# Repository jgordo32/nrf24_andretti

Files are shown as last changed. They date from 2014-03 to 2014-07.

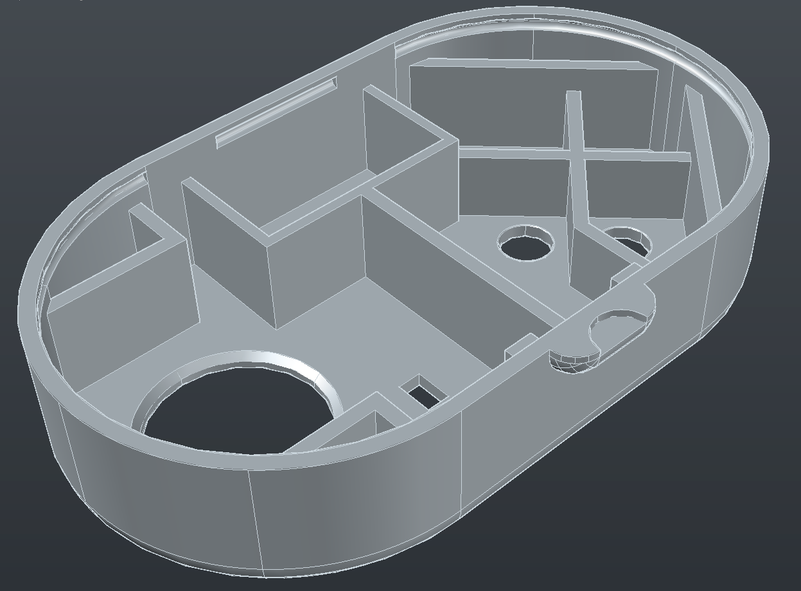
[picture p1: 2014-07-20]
Wireless Controller Case/Renderings/top3.png

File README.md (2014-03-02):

nrf24_andretti
==============

Firmware project for the wireless controllers on the Andretti Video Game Shirt

When the codebase is a little more mature, either each app or each folder will have it's own more thoroughly explained readme file as the FreeRTOS kernel does.

Authors:
Adam Feinstein
Jonathan Gordon

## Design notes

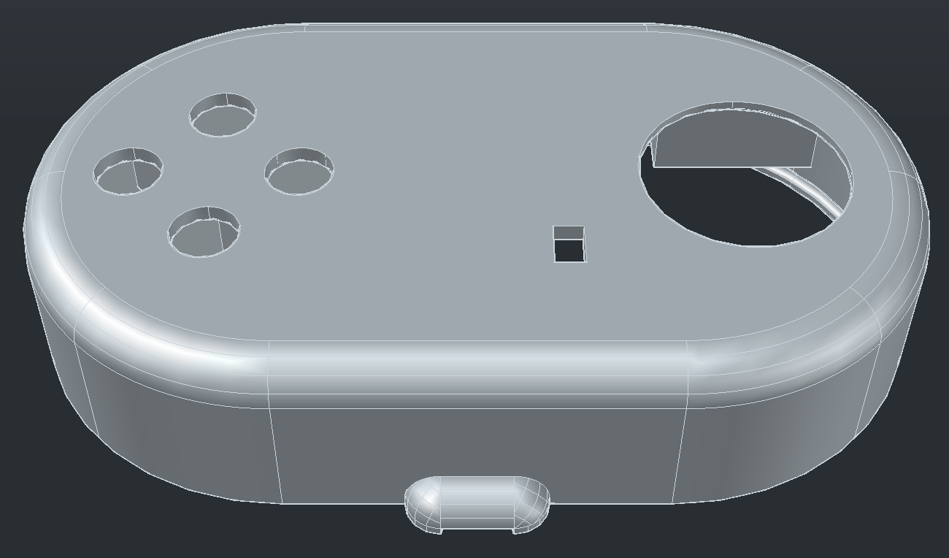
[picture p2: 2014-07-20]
Wireless Controller Case/Renderings/top1.png

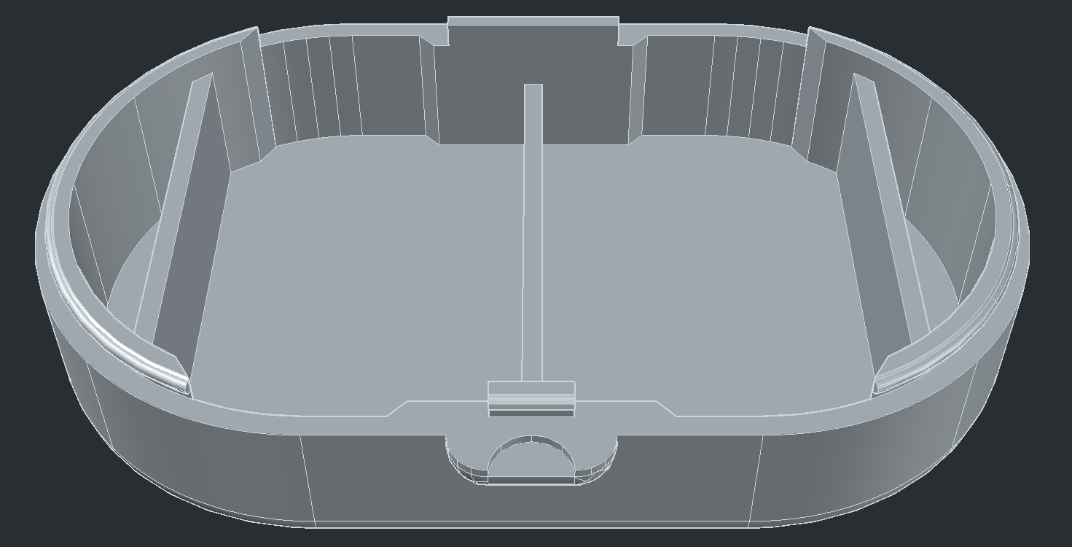
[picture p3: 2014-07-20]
Wireless Controller Case/Renderings/bottom1.png

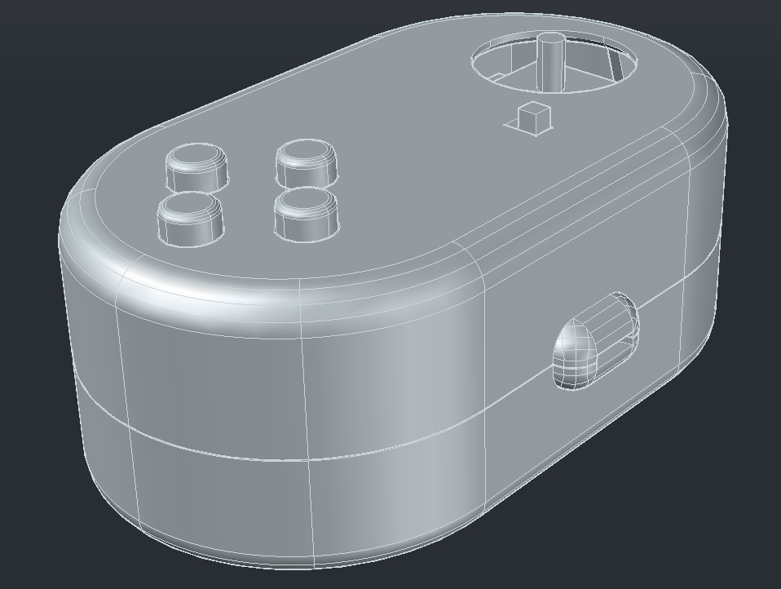
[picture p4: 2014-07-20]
Wireless Controller Case/Renderings/final2.png

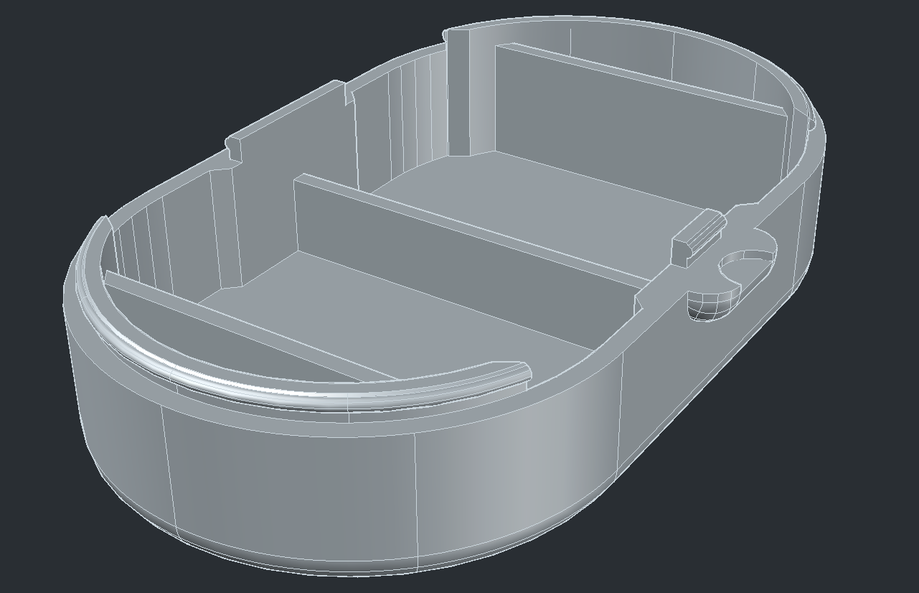
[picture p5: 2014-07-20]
Wireless Controller Case/Renderings/bottom2.png

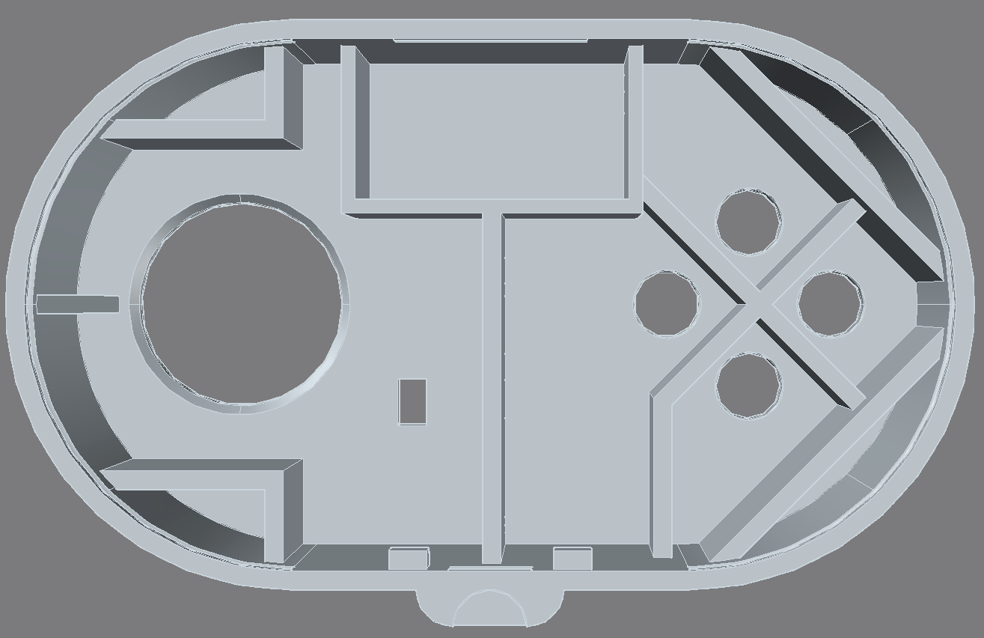
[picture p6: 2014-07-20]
Wireless Controller Case/Renderings/top2.png

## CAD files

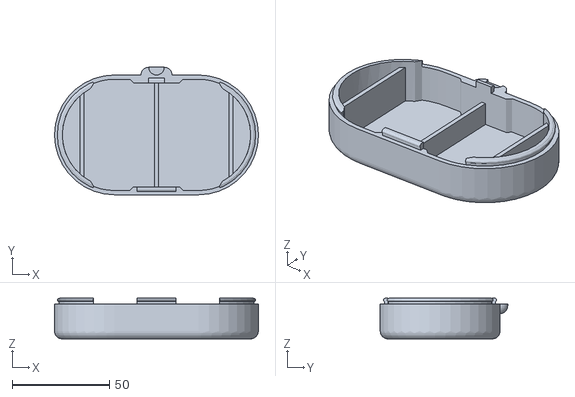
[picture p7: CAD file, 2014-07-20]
Wireless Controller Case/3D print/bottom.stl
104.7 x 65.5 x 21.0

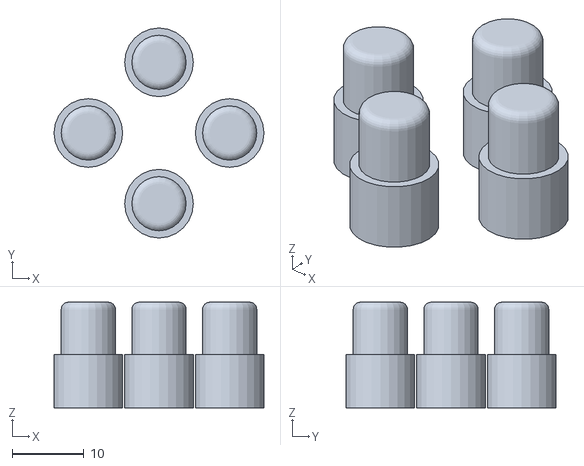
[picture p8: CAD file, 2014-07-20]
Wireless Controller Case/3D print/buttons.stl
29.2 x 29.2 x 14.7

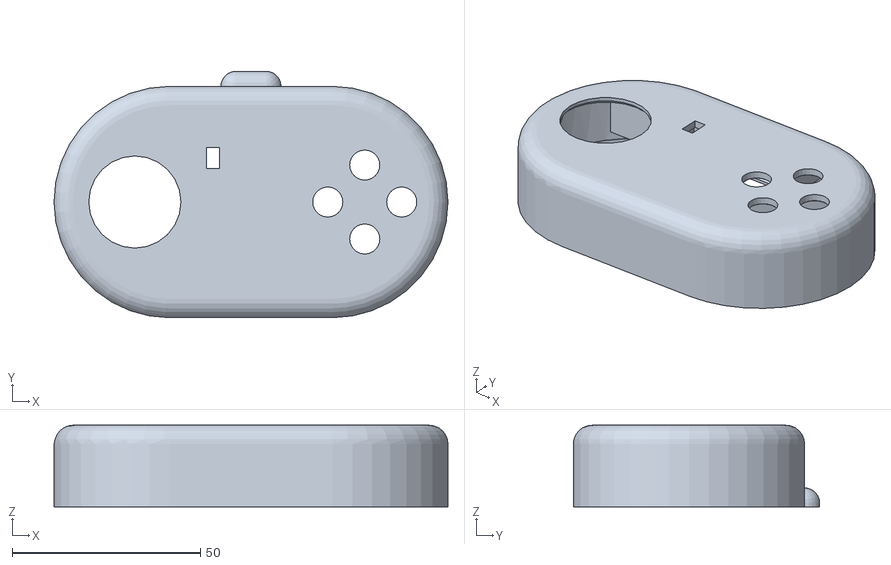
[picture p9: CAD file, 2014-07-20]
Wireless Controller Case/3D print/top.stl
104.7 x 65.5 x 21.7

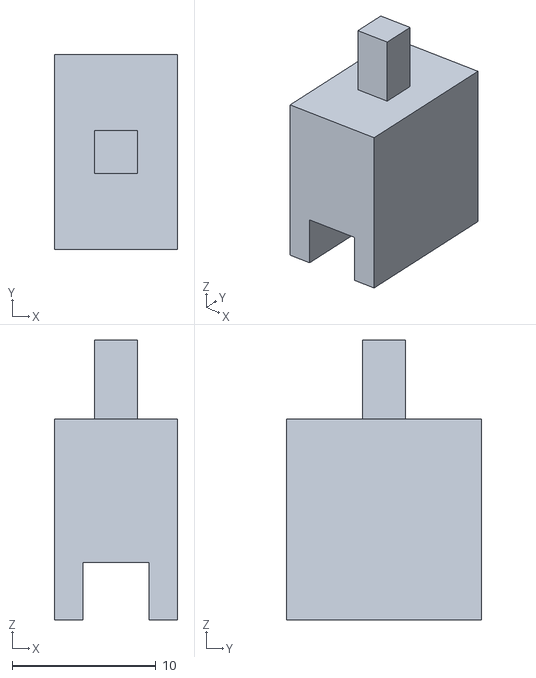
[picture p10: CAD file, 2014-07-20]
Wireless Controller Case/3D print/switch.stl
8.60 x 13.6 x 19.5

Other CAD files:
Wireless Controller Case/controller_case.dwg

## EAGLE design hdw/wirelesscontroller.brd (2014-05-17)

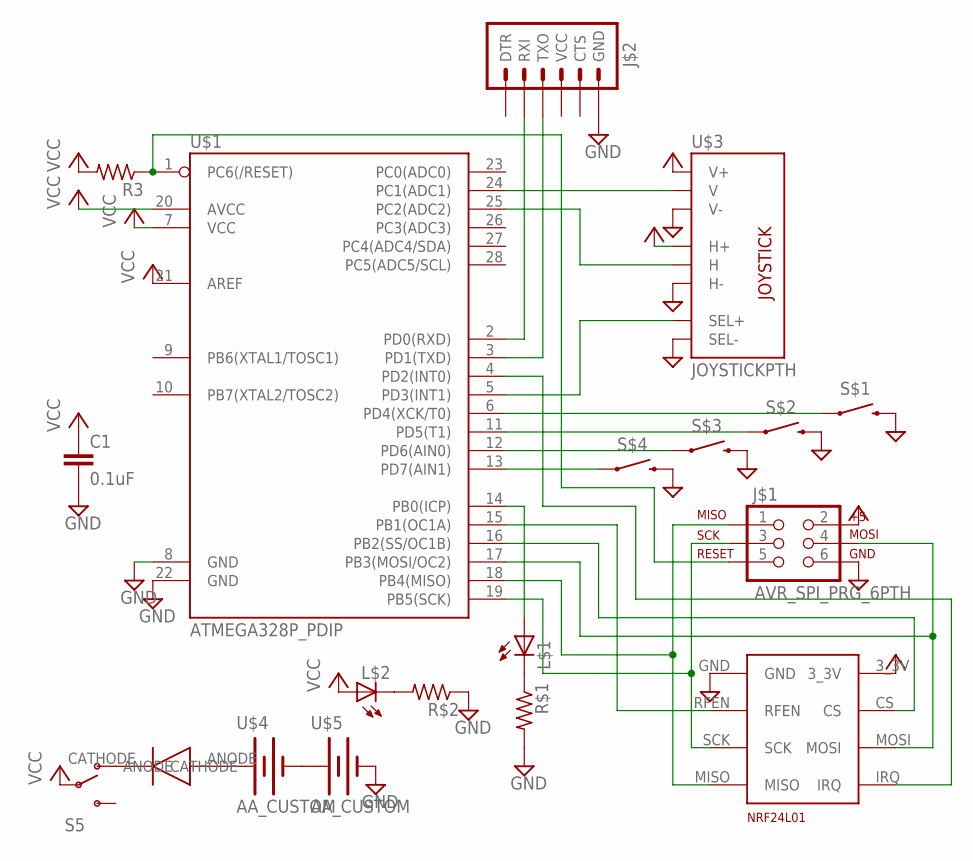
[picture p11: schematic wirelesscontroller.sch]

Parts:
C1: 0.1uF; 0603-CAP
D$1: DIODE; R0603
J$1: AVR_SPI_PRG_6PTH; 2X3
J$2: ARDUINO_SERIAL_PROGRAMPTH; 1X06
L$1, L$2: LEDCHIPLED_0603; CHIPLED_0603
R3: R-US_R0603; R0603
R$1, R$2: R-US_R0603; R0603
S5: SWITCH-SPDTPTH; SWITCH-SPDT
S$1, S$2, S$3, S$4: SWITCH-MOMENTARY-212MM; TACTILE-PTH-12MM
U$1: ATMEGA328P_PDIP; DIL28-3
U$2: NRF24L01_BRK; 4X2
U$3: JOYSTICKPTH; JOYSTICK
U$4, U$5: AA_CUSTOM; AACLIP

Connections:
AX: U$1.25 (PC2(ADC2)), U$3.H2 (H)
AY: U$1.24 (PC1(ADC1)), U$3.V2 (V)
B1: S$1.1, U$1.6 (PD4(XCK/T0))
B2: S$2.1, U$1.11 (PD5(T1))
B3: S$3.1, U$1.12 (PD6(AIN0))
B4: S$4.1, U$1.13 (PD7(AIN1))
B5: U$1.5 (PD3(INT1)), U$3.B1A (SEL+)
CS: U$1.16 (PB2(SS/OC1B)), U$2.CS
GND: C1.2, J$1.6, J$2.6 (GND), R$1.2, R$2.1, S$1.3 (2), S$2.3 (2), S$3.3 (2), S$4.3 (2), U$1.8 (GND), U$1.22 (GND), U$2.GND, U$3.B2A (SEL-), U$3.H3 (H-), U$3.V3 (V-), U$5.-
MISO: J$1.1, U$1.18 (PB4(MISO)), U$2.MISO
MOSI: J$1.4, U$1.17 (PB3(MOSI/OC2)), U$2.MOSI
unnamed: D$1.CATHODE, S5.1 (O)
unnamed: U$4.-, U$5.+
unnamed: D$1.ANODE, U$4.+
unnamed: L$2.C, R$2.2
unnamed: L$1.C, R$1.1
unnamed: L$1.A, U$1.14 (PB0(ICP))
RESET: J$1.5, R3.1, U$1.1 (PC6(/RESET))
RFEN: U$1.15 (PB1(OC1A)), U$2.RFEN
RF_IRQ: U$1.4 (PD2(INT0)), U$2.IRQ
RX: J$2.2 (RXI), U$1.2 (PD0(RXD))
SCK: J$1.3, U$1.19 (PB5(SCK)), U$2.SCK
TX: J$2.3 (TXO), U$1.3 (PD1(TXD))
VCC: C1.1, J$1.2, L$2.A, R3.2, S5.2, U$1.7 (VCC), U$1.20 (AVCC), U$1.21 (AREF), U$2.3_3V, U$3.H1 (H+), U$3.V1 (V+)

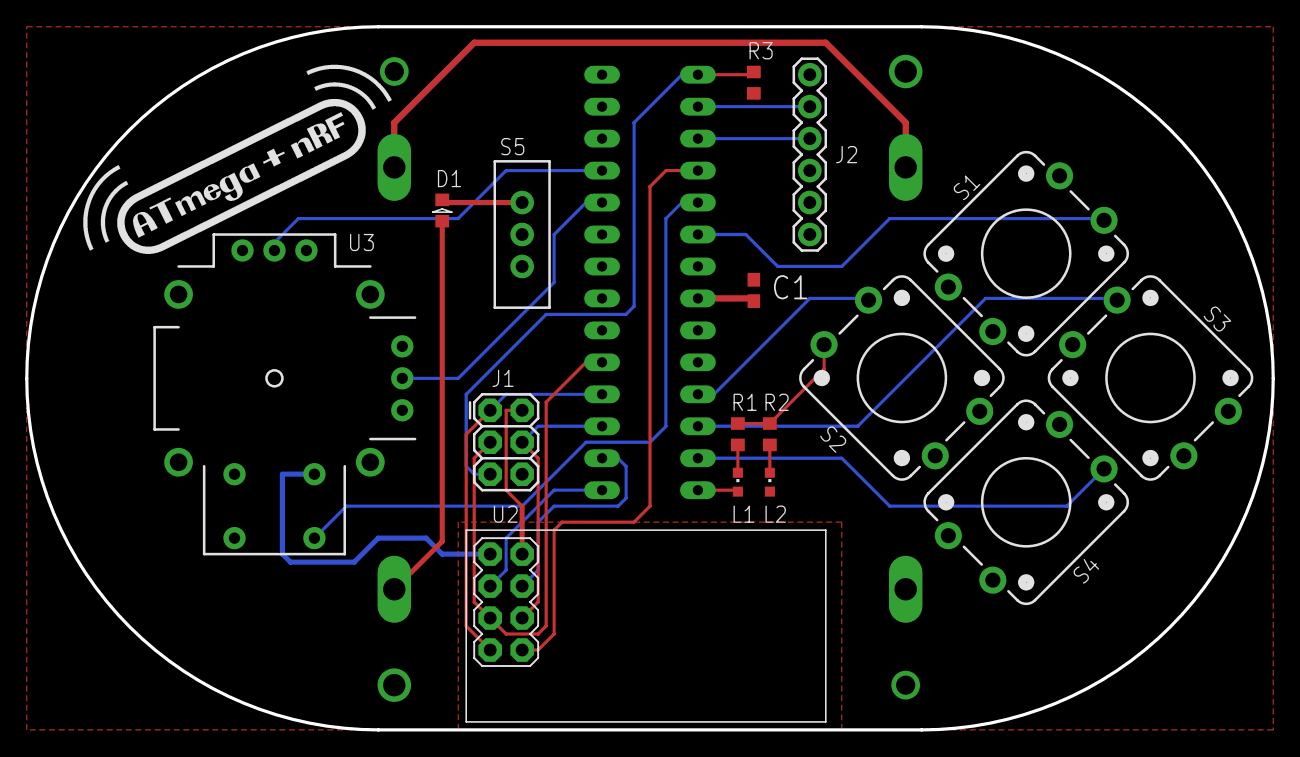
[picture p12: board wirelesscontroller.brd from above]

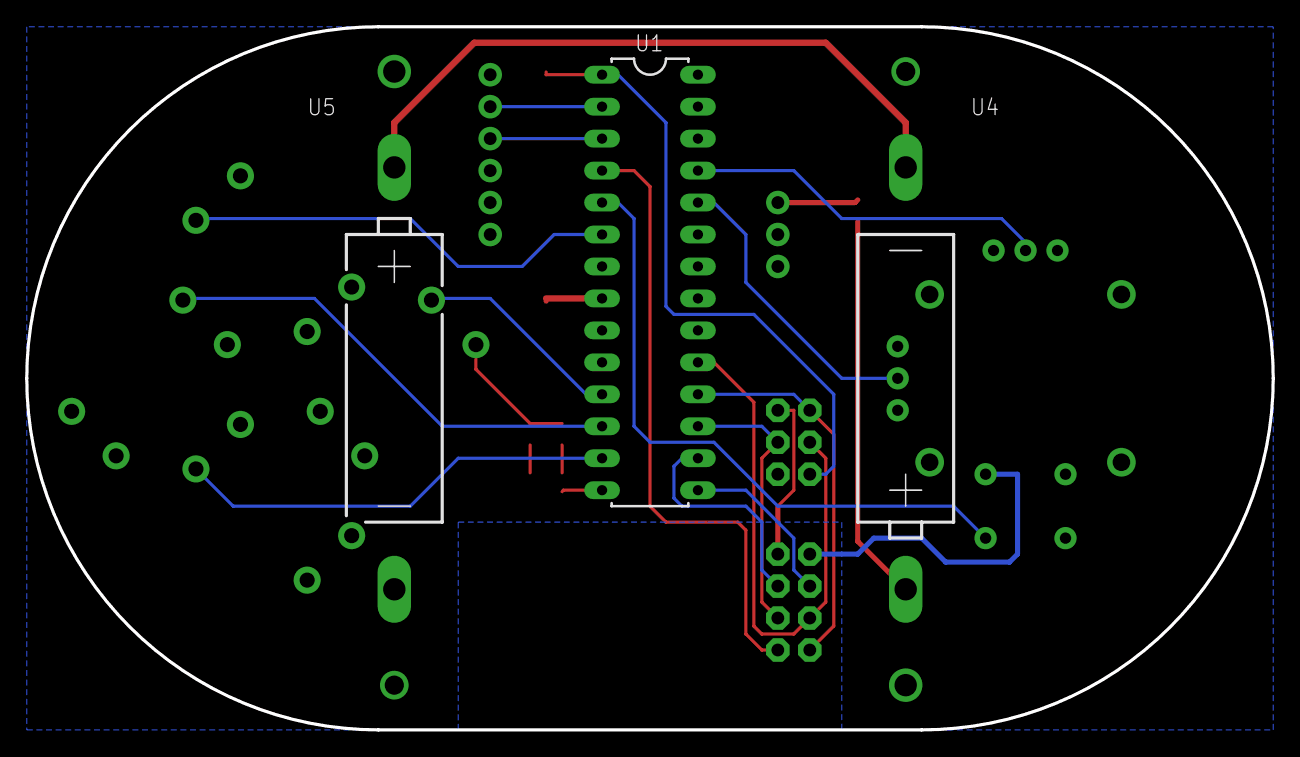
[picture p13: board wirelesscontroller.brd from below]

Board: 2 copper layers, 99.1 x 55.9 mm, 19 parts (3 on the bottom side), 24 nets.

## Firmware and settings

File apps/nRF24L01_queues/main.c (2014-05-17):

////////////////////////////////////////////////////////
////////////////////////////////////////////////////////
////    main.c 
////////////////////////////////////////////////////////
////////////////////////////////////////////////////////

#include <stdlib.h>
#include <string.h>
#include <math.h>
#include <stdio.h>
#include <avr/io.h>
#include <avr/pgmspace.h>
#include <util/delay.h>

/* Scheduler include files */
#include "FreeRTOS.h"
#include "task.h"
#include "queue.h"
#include "semphr.h"

/* Application specific includes */
#include "nrf24.h"
#include "config_types.h"

/* Local Function Prototypes */
void initPorts(void);
void initTimers(void);
void initRadio(void);

void taskHeartbeat2(void *pvParameters);
void radioTask(void *pvParameters);

static int uart_putchar(char c, FILE * stream);
static FILE debug_out = FDEV_SETUP_STREAM(uart_putchar, NULL, _FDEV_SETUP_WRITE);

/* Queue to hold rf transfer data */
xQueueHandle rfQueue;

//TODO: optimize these
/* nrf24 configuration parameters */
#define NRF24_CHANNEL_MHZ		15
#define NRF24_PAYLOAD_LEN		4

#if(BOARD_CONFIG == ARDUINO)
uint8_t ptxAddr[5] = {0xE7, 0xE7, 0xE7, 0xE7, 0xE7};
uint8_t prxAddr[5] = {0xD1, 0xD1, 0xD1, 0xD1, 0xD1};
#elif(BOARD_CONFIG == AVR)
uint8_t ptxAddr[5] = {0xD1, 0xD1, 0xD1, 0xD1, 0xD1};
uint8_t prxAddr[5] = {0xE7, 0xE7, 0xE7, 0xE7, 0xE7};
#endif

/* Main program loop */
int main(void)
{
    
#if 1
    /* Hardware initialization */
    initPorts();
    
    initTimers();
    initRadio();

    rfQueue = xQueueCreate(64, sizeof(uint8_t));  //64 byte queue for RF transfer data

    xTaskCreate(radioTask, (const signed portCHAR *)"Radio", 218, NULL, 2, NULL);
    xTaskCreate(taskHeartbeat2, (const signed portCHAR *)"Blink2", 48, NULL, 1, NULL);


    vTaskStartScheduler();
#else
    //Make PortB.0 an output
    DDRB |= _BV(0);
    while(1)
    {
        // Toggle PortB.0
        PORTB ^= _BV(0);
        _delay_ms(500);
    }    

    
#endif

    return 0;
}

void initRadio(void){
	nrf24_init();
	nrf24_config(NRF24_CHANNEL_MHZ, NRF24_PAYLOAD_LEN);//channel 15, 16 byte payload
	nrf24_tx_address(ptxAddr);
	nrf24_rx_address(prxAddr);

}

/* Blink the LED on PORTC.0 @ 1 Hz */
void taskHeartbeat2(void *pvParameters)
{
	(void) pvParameters;
	uint8_t odd = 0;
	const portTickType xDelay = 500 / portTICK_RATE_MS;
	while(1){
		if(odd)
			PORTB |= _BV(PORTB0);
		else
			PORTB &= ~_BV(PORTB0);
		odd = !odd;
		vTaskDelay(xDelay);
		printf("Heart-beat!\n");
	}
}

/* Send data using the nRF radio */
void radioTask(void *pvParameters)
{
	(void) pvParameters;
	uint8_t rfData[NRF24_PAYLOAD_LEN];
	uint8_t rcvData[NRF24_PAYLOAD_LEN];
	uint8_t pktCounter = 0;
	uint8_t blinkCounter = 0;
	const portTickType blinkDelay = 250 / portTICK_RATE_MS;
	const portTickType sendDelay = 5000 / portTICK_RATE_MS;

	rfData[0] = 0xB1;
	rfData[1] = 0x3A;
	rfData[2] = 0x23;
	while(1)
	{
		if(nrf24_dataReady())
		{
			nrf24_getData(rcvData);
			// Format message for debugging
			char debugRcvString[3*6] = {0};
			for (uint8_t i=0; i < NRF24_PAYLOAD_LEN; i++)
			{
				sprintf(debugRcvString+(3*i), "%02X ", rcvData[i]);
			}
			printf("Received: %s\n", debugRcvString);
		}


		rfData[3] = pktCounter++;
		nrf24_send(rfData);
		while(nrf24_isSending());
		char debugSendString[3*6] = {0};
		for (uint8_t i = 0; i < NRF24_PAYLOAD_LEN; i++)
		{
			sprintf(debugSendString+(3*i), "%02X ", rfData[i]);
		}
		printf("Sent: %s\n", debugSendString);

		if(nrf24_lastMessageStatus())
		{
			//there was a send problem
		}else{
			//transmission was ok
		}
		for(blinkCounter = 1 + nrf24_retransmissionCount(); blinkCounter > 0; --blinkCounter)
		{
			PORTC |= _BV(PORTC3);
			vTaskDelay(blinkDelay);
			PORTC &= ~_BV(PORTC3);
			vTaskDelay(blinkDelay);

		}

		nrf24_powerUpRx();
		vTaskDelay(sendDelay);

	}
}

/* Initialization Functions */

/* Init Ports */
void initPorts(void){
	// Port B initialization
    // 0 - output 	- LED
    // 1 - output 	- rfen						- nRF CE
    // 2 - output 	- /SS						- nRF CSN
    // 3 - output  	- MOSI						- nRF MOSI
    // 4 - input 	- MISO						- nRF MISO
    // 5 - output 	- SCK and arduino LED		- nRF SCK
    // 6 - output 	- NC
    // 7 - output 	- NC

	// DDRB
    // 0b1110 1111 	= 0xEF
	PORTB = 0x00;
	DDRB = 0xEF;

	/* Initialize the hardware SPI module after setting the /SS to output */
	SPCR |= (_BV(MSTR) | _BV(SPE)); //set to master and enable //enabling SPI messes up arduino LED which is on SCK line
	SPCR &= ~(_BV(CPOL) | _BV(CPHA) | _BV(DORD) | _BV(SPR0) | _BV(SPR1)); //set to mode0 with MSB first, f_clk/4
	SPSR |= SPI2X; //this divides min clk cycles by 2 so now SCK = f_clk/2


	// Port C initialization
    // 0 - output 	- NC
    // 1 - input 	- V potentiometer
    // 2 - input 	- H potentiometer
    // 3 - output 	- NC
    // 4 - output 	- NC
    // 5 - output 	- NC
    // 6 - input 	- pulled up, /RESET
    // 7 - output 	- NC

	// DDRC
	// 0b1011 1001	= 0xB9
	PORTC = 0x00;
	DDRC = 0xB9;

	// Port D initialization
    // 0 - input  	- uart RX
    // 1 - output  	- uart TX
    // 2 - input  	- RF interrupt INT0			- nRF IRQ
    // 3 - input 	- joystick button
    // 4 - input  	- button 1
    // 5 - input  	- button 2
    // 6 - input  	- button 3
    // 7 - input  	- button 4
    // NOTE: all buttons need to use internal pull-ups

	// DDRD
    // 0b0000 0010 	= 0x02
   	PORTD = 0x00;
	DDRD = 0x02;
    PORTD = 0xF8; /* Enable pull-ups on the highest 5 pins for the buttons */

	//TODO: don't hardcode this... make it baudrate generic from build settings maybe?
	/* Initialize the hardware UART */
	/* Set baud */
	uint16_t ubrr = 0;
#if(BOARD_CONFIG == ARDUINO)
	ubrr = ((configCPU_CLOCK_HZ / 16) / 57600) - 1;
#elif(BOARD_CONFIG == AVR)
	ubrr = ((configCPU_CLOCK_HZ / 16) / 4800) - 1;
#endif
	UBRR0H = (uint8_t)(ubrr >> 8);
	UBRR0L = (uint8_t)(ubrr);
	/* Enable the receiver and transmitter */
	UCSR0B = (_BV(RXEN0) | _BV(TXEN0));
	/* Set framing to 8N1 */
	UCSR0C = (_BV(UCSZ00) | _BV(UCSZ01));

	/* Initialize the global stream stdout */
	stdout = &debug_out;
}

/* Init Timers */
void initTimers(void){
	// Timer/Counter 0 initialization
	// Clock source: System Clock
	// Clock value: Timer 0 Stopped
	// Mode: Normal top=FFh
	// OC0 output: Disconnected
	// ASSR=0x00;
	// TCCR0=0x00;
	// TCNT0=0x00;
	// OCR0=0x00;

	// Timer/Counter 1 initialization
	// Mode: Normal top=FFFFh


	// OC1A output: Discon.
	// OC1B output: Discon.
	// OC1C output: Discon.
	TCCR1A=0x00;

	// Clock source: none               = 00
	// Clock source: system clock       = 01
	// Clock source: system clock/64    = 03
	// Clock source: system clock/256   = 04
	// Clock source: system clock/1024  = 05
	// Noise Canceler: Off
	// Input Capture on Falling Edge
	TCCR1B=0x00;

    // set the inital counts to zero
	TCNT1H=0x00;
	TCNT1L=0x00;

    // amount to compare the timer to
	OCR1AH=0x00;
	OCR1AL=0x00;

	OCR1BH=0x00;
	OCR1BL=0x00;


	// Timer/Counter 2 initialization
	// Clock source: T2 pin Rising Edge
	// Mode: Normal top=FFh
	// OC2 output: Disconnected
	TCCR2B=0x07;
	TCNT2=0x00;
	OCR2A=0x00;

}

/* Printing to UART function */
static int uart_putchar(char c, FILE * stream)
{
	if (c == '\n')
		uart_putchar('\r', stream);
	while(!(UCSR0A & _BV(UDRE0)));

    UDR0 = c;
    return 0;
}

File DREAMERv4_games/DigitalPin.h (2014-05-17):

/* Arduino DigitalPin Library
 * Copyright (C) 2012 by William Greiman
 *
 * This file is part of the Arduino DigitalPin Library
 *
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
 * You should have received a copy of the GNU General Public License
 * along with the Arduino DigitalPin Library.  If not, see
 * <http://www.gnu.org/licenses/>.
 */
/**
 * \file
 * \brief DigitalPin class
 */
#ifndef DigitalPin_h
#define DigitalPin_h
#include <avr/io.h>
#include <util/atomic.h>
//------------------------------------------------------------------------------
/** DigitalPin version YYYYMMDD */
#define DIGITAL_PIN_VERSION 20120804
//------------------------------------------------------------------------------
/**
 * \class pin_map_t
 * \brief struct for mapping digital pins
 */
struct pin_map_t {
  volatile uint8_t* ddr;   /**< address of DDR for this pin */
  volatile uint8_t* pin;   /**< address of PIN for this pin */
  volatile uint8_t* port;  /**< address of PORT for this pin */
  uint8_t bit;             /**< bit number for this pin */
};
//------------------------------------------------------------------------------
#if defined(__AVR_ATmega168__)\
||defined(__AVR_ATmega168P__)\
||defined(__AVR_ATmega328P__)
// 168 and 328 Arduinos
const static pin_map_t pinMap[] = {
  {&DDRD, &PIND, &PORTD, 0},  // D0  0
  {&DDRD, &PIND, &PORTD, 1},  // D1  1
  {&DDRD, &PIND, &PORTD, 2},  // D2  2
  {&DDRD, &PIND, &PORTD, 3},  // D3  3
  {&DDRD, &PIND, &PORTD, 4},  // D4  4
  {&DDRD, &PIND, &PORTD, 5},  // D5  5
  {&DDRD, &PIND, &PORTD, 6},  // D6  6
  {&DDRD, &PIND, &PORTD, 7},  // D7  7
  {&DDRB, &PINB, &PORTB, 0},  // B0  8
  {&DDRB, &PINB, &PORTB, 1},  // B1  9
  {&DDRB, &PINB, &PORTB, 2},  // B2 10
  {&DDRB, &PINB, &PORTB, 3},  // B3 11
  {&DDRB, &PINB, &PORTB, 4},  // B4 12
  {&DDRB, &PINB, &PORTB, 5},  // B5 13
  {&DDRC, &PINC, &PORTC, 0},  // C0 14
  {&DDRC, &PINC, &PORTC, 1},  // C1 15
  {&DDRC, &PINC, &PORTC, 2},  // C2 16
  {&DDRC, &PINC, &PORTC, 3},  // C3 17
  {&DDRC, &PINC, &PORTC, 4},  // C4 18
  {&DDRC, &PINC, &PORTC, 5}   // C5 19
};
//------------------------------------------------------------------------------
#elif defined(__AVR_ATmega1280__)\
|| defined(__AVR_ATmega2560__)
// Mega
static const pin_map_t pinMap[] = {
  {&DDRE, &PINE, &PORTE, 0},  // E0  0
  {&DDRE, &PINE, &PORTE, 1},  // E1  1
  {&DDRE, &PINE, &PORTE, 4},  // E4  2
  {&DDRE, &PINE, &PORTE, 5},  // E5  3
  {&DDRG, &PING, &PORTG, 5},  // G5  4
  {&DDRE, &PINE, &PORTE, 3},  // E3  5
  {&DDRH, &PINH, &PORTH, 3},  // H3  6
  {&DDRH, &PINH, &PORTH, 4},  // H4  7
  {&DDRH, &PINH, &PORTH, 5},  // H5  8
  {&DDRH, &PINH, &PORTH, 6},  // H6  9
  {&DDRB, &PINB, &PORTB, 4},  // B4 10
  {&DDRB, &PINB, &PORTB, 5},  // B5 11
  {&DDRB, &PINB, &PORTB, 6},  // B6 12
  {&DDRB, &PINB, &PORTB, 7},  // B7 13
  {&DDRJ, &PINJ, &PORTJ, 1},  // J1 14
  {&DDRJ, &PINJ, &PORTJ, 0},  // J0 15
  {&DDRH, &PINH, &PORTH, 1},  // H1 16
  {&DDRH, &PINH, &PORTH, 0},  // H0 17
  {&DDRD, &PIND, &PORTD, 3},  // D3 18
  {&DDRD, &PIND, &PORTD, 2},  // D2 19
  {&DDRD, &PIND, &PORTD, 1},  // D1 20
  {&DDRD, &PIND, &PORTD, 0},  // D0 21
  {&DDRA, &PINA, &PORTA, 0},  // A0 22
  {&DDRA, &PINA, &PORTA, 1},  // A1 23
  {&DDRA, &PINA, &PORTA, 2},  // A2 24
  {&DDRA, &PINA, &PORTA, 3},  // A3 25
  {&DDRA, &PINA, &PORTA, 4},  // A4 26
  {&DDRA, &PINA, &PORTA, 5},  // A5 27
  {&DDRA, &PINA, &PORTA, 6},  // A6 28
  {&DDRA, &PINA, &PORTA, 7},  // A7 29
  {&DDRC, &PINC, &PORTC, 7},  // C7 30
  {&DDRC, &PINC, &PORTC, 6},  // C6 31
  {&DDRC, &PINC, &PORTC, 5},  // C5 32
  {&DDRC, &PINC, &PORTC, 4},  // C4 33
  {&DDRC, &PINC, &PORTC, 3},  // C3 34
  {&DDRC, &PINC, &PORTC, 2},  // C2 35
  {&DDRC, &PINC, &PORTC, 1},  // C1 36
  {&DDRC, &PINC, &PORTC, 0},  // C0 37
  {&DDRD, &PIND, &PORTD, 7},  // D7 38
  {&DDRG, &PING, &PORTG, 2},  // G2 39
  {&DDRG, &PING, &PORTG, 1},  // G1 40
  {&DDRG, &PING, &PORTG, 0},  // G0 41
  {&DDRL, &PINL, &PORTL, 7},  // L7 42
  {&DDRL, &PINL, &PORTL, 6},  // L6 43
  {&DDRL, &PINL, &PORTL, 5},  // L5 44
  {&DDRL, &PINL, &PORTL, 4},  // L4 45
  {&DDRL, &PINL, &PORTL, 3},  // L3 46
  {&DDRL, &PINL, &PORTL, 2},  // L2 47
  {&DDRL, &PINL, &PORTL, 1},  // L1 48
  {&DDRL, &PINL, &PORTL, 0},  // L0 49
  {&DDRB, &PINB, &PORTB, 3},  // B3 50
  {&DDRB, &PINB, &PORTB, 2},  // B2 51
  {&DDRB, &PINB, &PORTB, 1},  // B1 52
  {&DDRB, &PINB, &PORTB, 0},  // B0 53
  {&DDRF, &PINF, &PORTF, 0},  // F0 54
  {&DDRF, &PINF, &PORTF, 1},  // F1 55
  {&DDRF, &PINF, &PORTF, 2},  // F2 56
  {&DDRF, &PINF, &PORTF, 3},  // F3 57
  {&DDRF, &PINF, &PORTF, 4},  // F4 58
  {&DDRF, &PINF, &PORTF, 5},  // F5 59
  {&DDRF, &PINF, &PORTF, 6},  // F6 60
  {&DDRF, &PINF, &PORTF, 7},  // F7 61
  {&DDRK, &PINK, &PORTK, 0},  // K0 62
  {&DDRK, &PINK, &PORTK, 1},  // K1 63
  {&DDRK, &PINK, &PORTK, 2},  // K2 64
  {&DDRK, &PINK, &PORTK, 3},  // K3 65
  {&DDRK, &PINK, &PORTK, 4},  // K4 66
  {&DDRK, &PINK, &PORTK, 5},  // K5 67
  {&DDRK, &PINK, &PORTK, 6},  // K6 68
  {&DDRK, &PINK, &PORTK, 7}   // K7 69
};
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

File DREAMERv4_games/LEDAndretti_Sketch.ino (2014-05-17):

#include <SPI.h>
#include "DigitalPin.h"
#include "ArduinoGame.h"
#include "Pong.h"
#include "Lightcycle.h"
#include "Life.h"
#include "TicTacToe.h"
#include "Tetris.h"
#include "ArduinoGame.h"

#define HEARTBEAT_IN_MAIN
//#define TEST_PATTERN
//#define SERIAL_PRINT
//#define IRQ_ENABLED

#define NUM_GAMES 5

#define PONG 0
#define TETRIS 1
#define LIGHTCYCLE 2
#define TICTACTOE 3
#define GAMEOFLIFE 4

unsigned char gameMode;
unsigned char downTimer;

#ifndef IRQ_ENABLED
unsigned long microsTimer;
unsigned long currTime;
#endif

// Function Declarations
void LEDShiftOut(byte IC5, byte IC3, byte IC4, byte IC6);
void UpdateGame(void);

// Variable Declarations
DigitalPin<7> latchPin;
DigitalPin<13> lightPin;

DigitalPin<P1_BL> p1bl;
DigitalPin<P1_BR> p1br;
DigitalPin<P1_BU> p1bu;
DigitalPin<P1_BD> p1bd;
DigitalPin<P2_BL> p2bl;
DigitalPin<P2_BR> p2br;
DigitalPin<P2_BU> p2bu;
DigitalPin<P2_BD> p2bd;

// LED field, currently treated as boolean, maybe brightness one day. Can PWM up to 1/8 without much flicker!
volatile unsigned char field[BOARD_SIZE][BOARD_SIZE];

// Heartbeat variables
unsigned long lastTick;
unsigned int toggle;

// Used for drawing the field
int i, j;
byte IC3, IC4, IC5, IC6;
unsigned long PWMcnt;

#ifdef TEST_PATTERN
int testCnt;
#endif

// Manage the Games
ArduinoGame* currentGame;

Pong pong;
Lightcycle lightcycle;
GameOfLife gameoflife;
TicTacToe tictactoe;
Tetris tetris;

void setup()
{
#ifdef SERIAL_PRINT
  Serial.begin(115200);
#endif

  // Seed the RNG
  randomSeed(analogRead(RANDOM_PIN));

  // Clear Variables
  memset((void*)field, 0, sizeof(field));
  lastTick = 0;
  toggle = 0;
  downTimer = 0;
  PWMcnt = 0;
#ifndef IRQ_ENABLED
  microsTimer = 0;
#endif

  gameMode = PONG;
  currentGame = &pong;
  currentGame->ResetGame(field,1,0);

#ifdef TEST_PATTERN
  testCnt = 0;
#endif

  // Enable pins
  latchPin.mode(OUTPUT);
  lightPin.mode(OUTPUT);

  // Internal pullups
  p1bl.mode(INPUT);
  p1bl.high();
  p1br.mode(INPUT);
  p1br.high();
  p1bu.mode(INPUT);
  p1bu.high();
  p1bd.mode(INPUT);
  p1bd.high();
  p2bl.mode(INPUT);
  p2bl.high();
  p2br.mode(INPUT);
  p2br.high();
  p2bu.mode(INPUT);
  p2bu.high();
  p2bd.mode(INPUT);
  p2bd.high();

  // initialize SPI:
  SPI.begin();
  SPI.setClockDivider(SPI_CLOCK_DIV2); // 8MHz

#ifdef IRQ_ENABLED
  // Set up interrupt
  cli();//stop interrupts
  toggle = 0;

  //set timer1 interrupt at IRQ_HZ Hz
  TCCR1A = 0;// set entire TCCR1A register to 0
  TCCR1B = 0;// same for TCCR1B
  TCNT1 = 0;//initialize counter value to 0
  // set compare match register for 1hz increments
  OCR1A = 15625/IRQ_HZ - 1;// (must be <65536) [16MHz / (1024 * IRQ_HZ) - 1]
  // turn on CTC mode
  TCCR1B |= (1 << WGM12);
  // Set CS10 and CS12 bits for 1024 prescaler
  TCCR1B |= (1 << CS12) | (1 << CS10);
  // enable timer compare interrupt
  TIMSK1 |= (1 << OCIE1A);

  sei();//allow interrupts
#endif
}

void loop()
{

#ifdef HEARTBEAT_IN_MAIN
  if(lastTick + 500 < millis()) {
    lastTick = millis();
    if(toggle == 1) {
      toggle = 0;
      lightPin.low();
    }
    else {
      toggle = 1;
      lightPin.high();
    }
  }
#endif

#ifndef IRQ_ENABLED
  currTime = micros();
  if(microsTimer + 1000000/IRQ_HZ < currTime) {
    // Clear the screen for processing
    LEDShiftOut(0x00, 0xFF, 0xFF, 0x00);
    microsTimer = currTime;
    UpdateGame();
  }
#endif
  // Writes 32 bits, 256 times, for a total of 8192 bits. @8MHz SPI, thats 1.024ms.
  // But we have to toggle the latch too, so each set of 32 bits takes 14.76 uS, for a total of 3.78ms
  // This interrupt can be called at most 264Hz (312Hz experimentally, but the LEDs slow down)

  // Iterate through all possible LEDs, flash them if they are on
  for (i = 0; i < BOARD_SIZE; i++) { // X axis, controls VCC
    for (j = 0; j < BOARD_SIZE; j++) { // Y axis, controls GND
      if (field[i][j] /*&& (PWMcnt % field[i][j] == 0)*/) {
        // GND, LSB
        IC3 = ((~(0x8000 >> j)) >> 8) & 0xFF;
        IC4 = ((~(0x8000 >> j)) >> 0) & 0xFF;

        // VCC, MSB
        IC5 = ((0x0001 << i) >> 0) & 0xFF;
        IC6 = ((0x0001 << i) >> 8) & 0xFF;

        LEDShiftOut(IC5, IC3, IC4, IC6);
      }
      else {
        LEDShiftOut(0x00, 0xFF, 0xFF, 0x00);
      }
    }
  }
  PWMcnt++;
}

#ifdef IRQ_ENABLED
//timer1 interrupt 60Hz
ISR(TIMER1_COMPA_vect)
{
  cli();// stop interrupts
  LEDShiftOut(0x00, 0xFF, 0xFF, 0x00);

  // Heartbeat
#ifndef HEARTBEAT_IN_MAIN
  toggle++;
  if (toggle == IRQ_HZ/2) {
    lightPin.high();
  }
  else if(toggle == IRQ_HZ) {
    lightPin.low();
    toggle = 0;
  }
#endif

  UpdateGame();

  sei();// enable interrupts
}
#endif

// First byte controls VCC towards jack
// Second byte controls GND towards jack
// Third byte controls GND away from jack
// Last byte controls VCC away from jack
void LEDShiftOut(byte IC5, byte IC3, byte IC4, byte IC6)
{
  // take the SS pin low to select the chip:
  latchPin.low(); // latch is held low for 14.76 uS
  // send in the address and value via SPI:
  SPI.transfer(IC5);
  SPI.transfer(IC3);
  SPI.transfer(IC4);
  SPI.transfer(IC6);
  // take the SS pin high to de-select the chip:
  latchPin.high();
}

void UpdateGame(void)
{

#ifdef TEST_PATTERN
  field[testCnt%BOARD_SIZE][testCnt/BOARD_SIZE] = 0;
  testCnt = (testCnt+1)%(BOARD_SIZE*BOARD_SIZE);
  field[testCnt%BOARD_SIZE][testCnt/BOARD_SIZE] = 0xFF;
#else

  if(!p1bu.read() && !p2bu.read()) {
    downTimer++;
  }
  else {
    downTimer = 0;
  }

  if(downTimer == IRQ_HZ * 2) {
    downTimer = 0;
    gameMode = (gameMode+1)%NUM_GAMES;
    switch(gameMode) {
      case PONG:
        currentGame = &pong;
        break;
      case LIGHTCYCLE:
        currentGame = &lightcycle;
        break;
      case GAMEOFLIFE:
        currentGame = &gameoflife;
        break;
      case TICTACTOE:
        currentGame = &tictactoe;
        break;
      case TETRIS:
        currentGame = &tetris;
        break;
    }
    currentGame->ResetGame(field,1,0);
  }

  currentGame->ProcessInput(field,
                            analogRead(P1_X), analogRead(P1_Y),
                            !p1bl.read(), !p1br.read(), !p1bu.read(), !p1bd.read(),
                            analogRead(P2_X), analogRead(P2_Y),
                            !p2bl.read(), !p2br.read(), !p2bu.read(), !p2bd.read());
  currentGame->UpdatePhysics(field);
#endif
}

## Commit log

2014-03-02 Adding Arduino, atmega328p, and FreeRTOS filesdhf
    - Updated the .gitignore to ignore dependency files
    - Added the initial Arduino POC code files
    - Added a POC version of the standalone AVR code
    - Added a pretty solid version of the AVR FreeRTOS port for the mega328P
    NOTE: completely untested at this point besides original POC testing
    01/2014
    [TcfTransactionLog.csv]
2014-03-03 Adding the hardware files
    - Added the Eagle sch and brd files for the wireless controller
    [wirelesscontroller.brd, wirelesscontroller.sch]
2014-03-04 Added bypass cap
    Added a bypass capacitor to the power supply on the controller
    [wirelesscontroller.brd, wirelesscontroller.sch]
2014-05-17 Stable-ish heartbeat on the controller board with radio code seemingly working.
2014-07-14 AutoCAD file for controller case
    File contains the 3D models I made for the PCB, components, buttons,
    switches, and top & bottom plastic pieces.
    [controller_case.dwg]
2014-07-14 Stereolithography files for 3D printing
    .stl files for the plastic components of the case.
    [bottom.stl, buttons.stl, switch.stl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]
2014-07-14 Renderings of controller case
    Renderings for various components of the 3D printed case.

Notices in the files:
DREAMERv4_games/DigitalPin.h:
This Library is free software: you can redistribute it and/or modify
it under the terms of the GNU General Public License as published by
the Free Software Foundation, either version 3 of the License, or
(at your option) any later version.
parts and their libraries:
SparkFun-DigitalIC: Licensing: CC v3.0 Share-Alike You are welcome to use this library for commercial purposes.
